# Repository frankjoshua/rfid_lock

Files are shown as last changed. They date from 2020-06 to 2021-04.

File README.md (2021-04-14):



## Usage of Lock

Just tap your rfid card to the reader. The reader will call a web service that will verify the membership status. If OK the pin D0 will go from LOW to HIGH. This will trigger a relay and allow power to the tool. A 5 minute timer will then start. If the lock detects current flowing above a set threshold the timer will reset. This prevents the lock from turning power off while the tool is in use. After the timer completes the count down (5 minutes of not using the tool). The pin D0 will go back to LOW releasing the relay and cutting power to the tool.

## Wiring Diagram

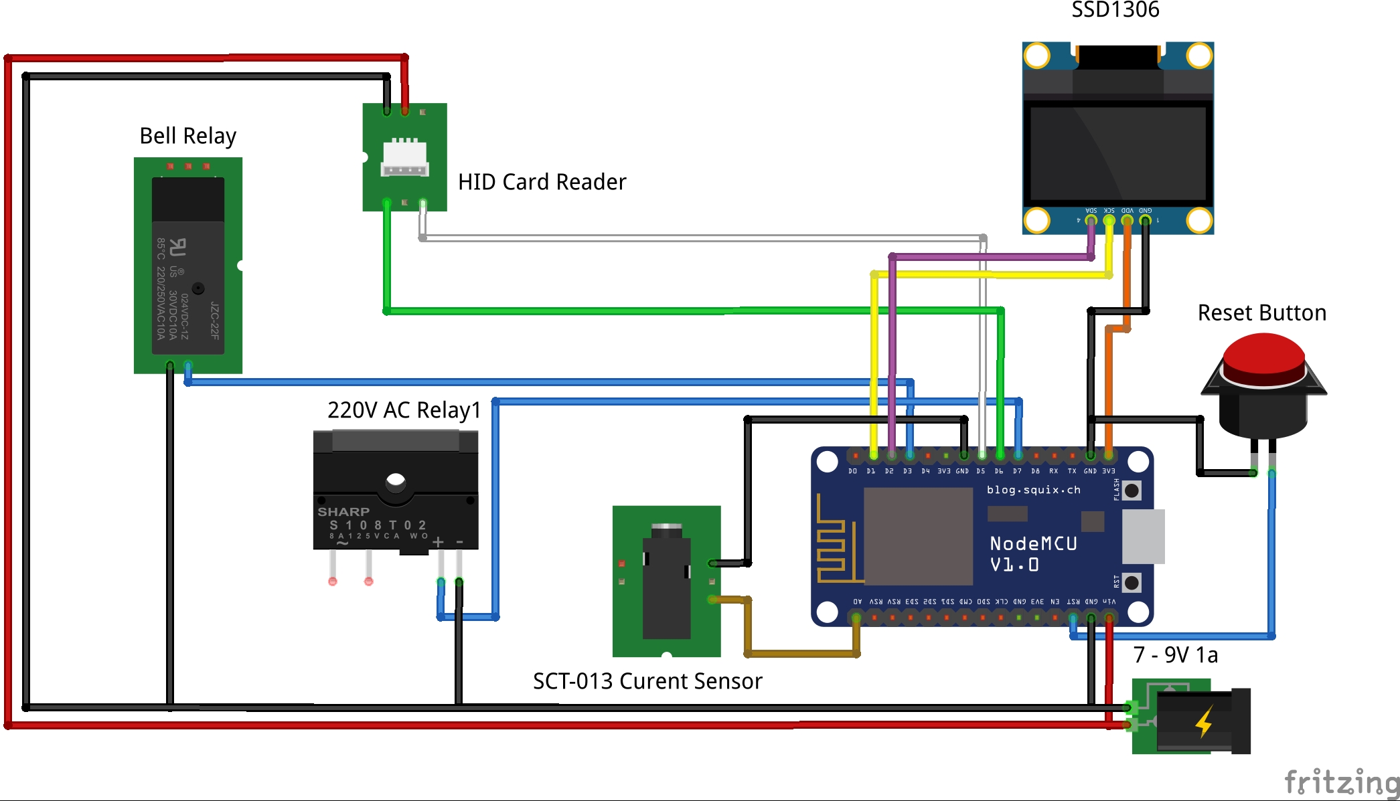
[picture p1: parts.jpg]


### External connections

RED - +9V (tolerant 7.5V to 10V)<br>
BLACK - Ground<br>
White - RELAY<br>
GREEN - SCT-013 Current Sensor
D3 (Optional) - Connects to Doorbell

## Initial Setup of Wifi and Asset tag

If the esp does not have a password for any available SSID it will then create its own access point named "ArchReactorLockout". Connect to that access point from a phone or computer. Then connect to http://192.168.4.1 This will display a config webpage. Click on "Configure WiFi" then add the correct SSID and password for your router. The esp will then reboot and connect to the WiFi access point that was configured. The last octet of the ip address will be displayed on the screen. You can use this address to configure the asset tag.

```
http://<IP_ADDRESS>/config?assetTag=<ASSET_TAG_ID>&key=<SECRET_KEY>
```

The first time you connect it will accept any secret key (string under 48 characters). That key will from that point need to be used to change settings. To set a new key use.

```
http://<IP_ADDRESS>/config?assetTag=<ASSET_TAG_ID>&key=<SECRET_KEY>&newKey=<NEW_SECRET_KEY>
```

The time the tool is unlocked can be changed. For example if using with a door lock you can set the unlock time to a very short duration. The duration is in milliseconds.

```
http://<IP_ADDRESS>/config?unlockDuration=5000&key=<SECRET_KEY>
```

<br>
Note the esp8266 must be on the same network as the server for security purposes. The server will reject all non local authentication requests without review.

## Locking and unlocking remotely

An administrator may remotely lock or unlock the tools.

```
http://<IP_ADDRESS>/lock?key=<SECRET_KEY>
http://<IP_ADDRESS>/unlock?key=<SECRET_KEY>
```

## OTA Updates

```
http://<IP_ADDRESS>/upload?key=<SECRET_KEY>
```

When you visit this URL it will start the OTA server and redirect you to /update. You can the browse for the bin file that should be in <WORKSPACE>/rfid_lock/rfid_platform_io/.pio/build/nodemcuv2/frimware.bin

## Testing

Testing is done automatically using Github Actions. It only tests that don't require a Nodemcu physically connected though.<br>
<br>
Manually run tests with.

```
cd rfid_platform_io
pio test -e test
```

This command will run tests on the Nodemcu if one is connected.

```
cd rfid_platform_io
pio test -e nodemcuv2
```

## Parts list

- [nodemcu (esp8266)](https://amz.run/3Mu4)
- [0.96" oled display](https://amz.run/3Mu5)
- [SCT-013 AC Current Sensor](https://amz.run/3Mu6)
- [RFID card Reader](https://amz.run/3MuC)
- [ABS Project Box](https://amz.run/3Mu7)
- [PCB Prototype Board](https://amz.run/3NYz)
- [3.5mm PCM mount Jacks](https://amz.run/3MuA)
- [220V to 7-10v 1 amp power supply (Needed)](https://amz.run/3Ugt)
- PCB and wires and terminals

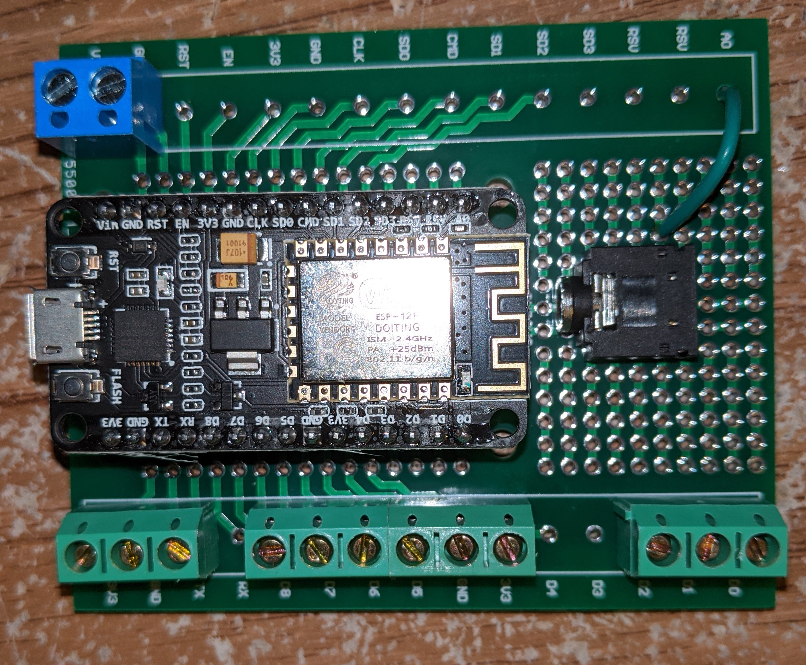
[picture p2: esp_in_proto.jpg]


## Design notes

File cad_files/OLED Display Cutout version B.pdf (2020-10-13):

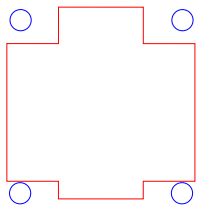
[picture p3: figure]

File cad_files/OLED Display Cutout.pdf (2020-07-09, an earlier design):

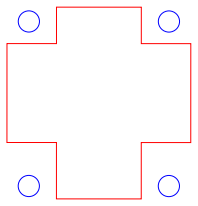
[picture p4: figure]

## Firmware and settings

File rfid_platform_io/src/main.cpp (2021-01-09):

#include <Arduino.h>
#include "rfid_reader.h"
#include "backoff.h"
#include "display.h"
#include "current.h"
#include "status.h"
#include "storage.h"
#include <ESP8266WiFi.h>
#include <ESP8266HTTPClient.h>
#include <ESPAsyncWiFiManager.h>
#include <ESPAsyncTCP.h>
#include <ESPAsyncWebServer.h>
#include <AsyncElegantOTA.h>

AsyncWebServer server(80);
DNSServer dns;
AsyncWiFiManager wifiManager(&server, &dns);
RfidReader rfidReader;
BackoffTimer backoff;
BackoffTimer currentSensorBackoff;
Display display;
CurrentSensor currentSensor;
Status status;
Storage storage;

#define RELAY_PIN D7
#define BELL_PIN D3

const String TOOL_CHECKOUT_URL = "https://api.archreactor.net";

unsigned long lockAtTime = 0;

void relayOn()
{
  digitalWrite(RELAY_PIN, HIGH);
}

void relayOff()
{
  digitalWrite(RELAY_PIN, LOW);
}

void bellOn()
{
  digitalWrite(BELL_PIN, HIGH);
}

void bellOff()
{
  digitalWrite(BELL_PIN, LOW);
}

void displayMessage(String msg)
{
  status.msg = msg;
  display.print(&status);
  Serial.println(msg);
}

void displayError(String msg)
{
  status.msg = "Error";
  status.error = msg;
  display.print(&status);
  Serial.println(msg);
}

void readCard()
{
  if (millis() % 1000 == 0)
  {
    displayMessage("");
  }
  if (rfidReader.isCardAvailable())
  {
    status.cardId = rfidReader.getCardId();
    if (status.cardId.length() <= 2)
    {
      if (status.cardId == "d")
      {
        status.mode = MODE_RING_BELL;
      }
    }
    else
    {
      status.mode = MODE_CALL_WEBHOOK;
    }
    backoff.reset();
    displayMessage("Please wait");
  }
}

void lock()
{
  relayOff();
  status.mode = MODE_READ;
}

void unlock()
{
  status.mode = MODE_UNLOCKED;
  lockAtTime = millis() + status.unlockDuration;
  backoff.reset();
}

void webhook()
{
  if (WiFi.status() != WL_CONNECTED)
  {
    displayError("No WIFI!");
    backoff.setDelay(millis());
    return;
  }

  HTTPClient http;
  WiFiClientSecure client;
  client.setInsecure(); //the magic line, use with caution
  String checkoutUrl = TOOL_CHECKOUT_URL + "/tool/" + status.assetTag + "/checkout/" + status.cardId;
  bool httpInitResult = http.begin(client, checkoutUrl);
  if (!httpInitResult)
  {
    displayError("Could not init http!");
    backoff.setDelay(millis());
    return;
  }

  int httpCode = http.GET();
  char error[256];
  switch (httpCode)
  {
  case 404: // User not found
  case 401: // User not authorized
  case 500: // Server Error Unknown
    displayMessage("Denied: " + String(httpCode));
    status.mode = MODE_READ;
    backoff.setDelay(millis());
    backoff.setDelay(millis());
    status.error = "Denied: " + String(httpCode) + " " + checkoutUrl;
    break;
  case 200:
    status.error = "";
    unlock();
    break;
  case 301: // http redirect still unlock
  case -1:  // Connection Refused - Server Down - Still unlock
  default:
    sprintf(error, "%s\n%d", http.errorToString(httpCode).c_str(), httpCode);
    status.error = error;
    unlock();
    break;
  }

  http.end();
  backoff.setDelay(millis());
}

void webhookCheckIn()
{
  if (WiFi.status() != WL_CONNECTED)
  {
    displayError("No WIFI!");
    backoff.setDelay(millis());
    return;
  }

  WiFiClientSecure client;
  client.setInsecure(); //the magic line, use with caution
  HTTPClient http;
  bool httpInitResult = http.begin(client, TOOL_CHECKOUT_URL + "/tool/" + status.assetTag + "/checkin");
  if (!httpInitResult)
  {
    displayError("Could not init http!");
    backoff.setDelay(millis());
    return;
  }

  int httpCode = http.GET();
  char error[256];
  switch (httpCode)
  {
  case 200: // OK
    lock();
    break;
  case 404: // User not found
  case 401: // User not authorized
  case 500: // Server Error Unknown
  case 301: // Http redirect
  case -1:  // Connection Refused
  default:
    sprintf(error, "%s\n%d", http.errorToString(httpCode).c_str(), httpCode);
    status.error = error;
    lock();
    break;
  }

  http.end();
  backoff.setDelay(millis());
}

String timeToString(unsigned long t)
{
  static char str[5];
  t = t % 3600;
  int m = t / 60;
  int s = t % 60;
  sprintf(str, "%01d:%02d", m, s);
  return String(str);
}

void unlockLoop()
{
  backoff.reset();
  backoff.setDelay(millis());
  if (status.current > 0.2)
  {
    lockAtTime = millis() + status.unlockDuration;
  }
  int timeLeft = (lockAtTime - millis()) / 1000;
  if (timeLeft > 0)
  {
    relayOn();
    displayMessage(timeToString(timeLeft) + " " + String(status.current) + "A");
  }
  else
  {
    status.mode = MODE_CALL_WEBHOOK_DISCONNECT;
  }
}

void updateLoop()
{
  unsigned long time = millis();
  if (time % 1500 == 0)
  {
    displayMessage("......");
  }
  else if (time % 1000 == 0)
  {
    displayMessage("....");
  }
  else if (time % 500 == 0)
  {
    displayMessage(".");
  }
  AsyncElegantOTA.loop();
}

void ringBellLoop()
{
  for (int i = 0; i < 5; i++)
  {
    bellOn();
    delay(150);
    bellOff();
    delay(50);
  }
  status.mode = MODE_READ;
}

/*
* True is Request has correct Key or if Key is not required
*/
bool hasValidKey(AsyncWebServerRequest *request)
{
  if (status.secretKey != "")
  {
    return request->hasArg("key") && status.secretKey == request->arg("key");
  }
  return true;
}

void setup()
{
  Serial.println("Initalizing display.");
  display.initDisplay();
  displayMessage("Starting ...");

  pinMode(RELAY_PIN, OUTPUT);
  pinMode(BELL_PIN, OUTPUT);
  relayOff();
  bellOff();

  Serial.begin(115200);
  while (!Serial)
  {
  }
  delay(2000);

  storage.restore(&status);
  displayMessage("<<Wifi>> ...");
  wifiManager.autoConnect("ArchReactorLockout");
  displayMessage("");

  server.on("/", HTTP_GET, [](AsyncWebServerRequest *request) {
    status.current = currentSensor.getCurrentInAmps();
    request->send(200, "application/json", status.getStateJson());
  });

  server.on("/config", HTTP_GET, [](AsyncWebServerRequest *request) {
    if (request->hasArg("key"))
    {
      if (status.secretKey == "" || status.secretKey == request->arg("key"))
      {
        if (request->hasArg("assetTag"))
        {
          status.assetTag = request->arg("assetTag");
        }
        if (request->hasArg("newKey"))
        {
          status.secretKey = request->arg("newKey");
        }
        if (request->hasArg("unlockDuration"))
        {
          status.unlockDuration = request->arg("unlockDuration").toInt();
        }
      }
      else
      {
        request->send(401, "application/json", status.getStateJson());
        return;
      }
    }
    else
    {
      request->send(400, "application/json", status.getStateJson());
      return;
    }
    storage.save(&status);
    status.current = currentSensor.getCurrentInAmps();
    request->send(200, "application/json", status.getStateJson());
  });

  server.on("/lock", HTTP_GET, [](AsyncWebServerRequest *request) {
    // Check for valid key
    if (!hasValidKey(request))
    {
      status.error = "401 Bad Key /lock";
      request->send(401, "application/json", status.getStateJson());
      return;
    }
    lock();
    request->send(200, "application/json", status.getStateJson());
  });

  server.on("/unlock", HTTP_GET, [](AsyncWebServerRequest *request) {
    status.cardId = "remote";
    // Check for valid key
    if (!hasValidKey(request))
    {
      status.error = "401 Bad Key /unlock";
      request->send(401, "application/json", status.getStateJson());
      return;
    }
    if (request->hasArg("cardId"))
    {
      status.cardId = request->arg("cardId");
      status.mode = MODE_CALL_WEBHOOK;
    }
    else
    {
      unlock();
    }
    request->send(200, "application/json", status.getStateJson());
  });

  server.on("/upload", HTTP_GET, [](AsyncWebServerRequest *request) {
    // Check for valid key
    if (!hasValidKey(request))
    {
      status.error = "401 Bad Key /upload";
      request->send(401, "application/json", status.getStateJson());
      return;
    }
    AsyncElegantOTA.begin(&server); // Start ElegantOTA
    status.mode = MODE_UPDATE;
    backoff.reset();
    request->send(200, "text/html", "<meta http-equiv=\"refresh\" content=\"2; url=/update\" /><H1>Waiting 2 seconds for update server to start...</H1>");
  });

  server.begin();

  // Ready to read cards
  status.mode = MODE_READ;
  Serial.println(WiFi.dnsIP());
  IPAddress result;
  int err = WiFi.hostByName("api.archreactor.net", result);
  if (err == 1)
  {
    Serial.print("Ip address: ");
    Serial.println(result);
  }
  else
  {
    Serial.print("Error code: ");
    Serial.println(err);
  }
  display.print(&status);
}

void loop()
{

  if (backoff.isReady(millis()))
  {
    switch (status.mode)
    {
    case MODE_READ:
      readCard();
      break;
    case MODE_CALL_WEBHOOK:
      webhook();
      break;
    case MODE_CALL_WEBHOOK_DISCONNECT:
      webhookCheckIn();
      break;
    case MODE_UNLOCKED:
      if (currentSensorBackoff.isReady(millis()))
      {
        currentSensorBackoff.reset();
        currentSensorBackoff.setDelay(millis());
        currentSensorBackoff.setDelay(millis());
        status.current = currentSensor.getCurrentInAmps();
      }
      unlockLoop();
      break;
    case MODE_UPDATE:
      updateLoop();
      break;
    case MODE_RING_BELL:
      ringBellLoop();
      break;
    }
  }
}

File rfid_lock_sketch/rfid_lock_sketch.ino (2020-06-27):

/**
 * Requirements:
 * https://github.com/tzapu/WiFiManager
 * https://github.com/monkeyboard/Wiegand-Protocol-Library-for-Arduino
 * https://github.com/adafruit/Adafruit_SSD1306
 * https://github.com/adafruit/Adafruit-GFX-Library
 * https://github.com/bblanchon/ArduinoJson
 */
#include "status.h"
#include <ESP8266WiFi.h>

//const char* AP_NAME = "RFIDLOCK_1";

void setup() {
  Serial.begin(9600);

  delay(100);
  initDisplay();
  setMessage("Booting...");
  delay(1000);
  initRFIDReader();
  initLock();
  String msg = String("No Wifi!\nAP SSID:\n");
  setMessage(msg);
  initWifi();
//  setMessage("Updating Card Database");
//  updateRepository();
  initFiles();
  setMessage(WiFi.localIP().toString());
}

void loop() {
  serverLoop();
  
  long timeElapsed = getTimeElapsed();

  if(isUnlocked()){
    updateTimeTillLock(timeElapsed);
    if(isTimeToLock()){
      setLocked();
    }
  }
  
  if(isCardPresent()){
//    updateCardId();
//    if(isCardAuthorized()){
//      setMessage("Authorized");
//      setUnlocked();
//    } else {
//      setLocked();
//      updateRepository(getApiKey(), getUserKey(), currentCardId());
//      if(isCardAuthorized()){
//        setMessage("Authorized");
//        setUnlocked();
//      }
//    }
  }

  if(shouldUpdateState()){
    updateLockAndDisplay();
  }

}

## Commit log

2020-01-19 Added parts diagram
    [parts.fzz]
2020-06-29 Changed pin numbers
2020-07-03 Updated schematic
    [parts.fzz]
2020-07-03 Updated sketch code
    [parts.fzz]
2020-07-04 Added adc to parts image
    [parts.fzz]
2020-07-05 Added parts list
    [parts.fzz]
2020-07-08 Added current sensor
    [parts.fzz]
2020-07-09 Added cad files
2020-08-16 Updated part diagram
    [parts.fzz]
2020-08-16 Added link to power supply
2020-09-16 Now handling 301 errors
    [main.cpp]
2020-11-10 Added bell
    [parts.fzz]
2021-01-04 Change relay pin to D7
    [parts.fzz]
2021-01-10 Added reset button to diagram
    [parts.fzz]
